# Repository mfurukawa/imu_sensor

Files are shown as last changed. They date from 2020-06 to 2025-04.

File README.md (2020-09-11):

# imu_sensor
Eagle PCB, mbed source code included.

- September 9, 2020 - changed Python code and mbed Protocol / Yuto Nakayachi 
- July  3, 2020 - Python, Unity, C# sample added / Masahiro Furukawa
- June 26, 2020 - created / Masahiro Furukawa

Masahiro Furukawa / Yuto Nakayachi

# mbed Protocol 

# for 4Ch MPU-9250 Sensor Module 

mbed Source Code

https://os.mbed.com/users/nakataniuchi/code/MPU9250_CH4_3_0_0/

see main.cpp

https://os.mbed.com/users/nakataniuchi/code/MPU9250_CH4_3_0_0//file/cdeed96f97fc/main.cpp/

# How to check mbed response

1. Open terminal software.
2. Set baudrate as 921600bps.
3. Set linefeed as “LF” only.
4. Press reset button on mbed.
5. If you see some message, mbed works.
6. Press ‘s’ key and you will see the data stream
7. Press ‘r’ key and it will stop.

# Protocol for ver 3.0.0

Byte order is **Big** Endian

for Header : 1 bytes = 8 bits describes 1 value 

<td>*</td> : header 

for Acceleration  : 2 bytes = 16 bits describes 1 value

Higher Byte 

A<sub>x, i</sub> : acceleration on axis X of ch i

A<sub>y, i</sub> : acceleration on axis Y of ch i 

A<sub>z, i</sub> : acceleration on axis Y of ch i 

Lower Byte

a<sub>x, i</sub> : acceleration on axis X of ch i 

a<sub>y, i</sub> : acceleration on axis Y of ch i 

a<sub>z, i</sub> : acceleration on axis Z of ch i 

for Angular Velocity  : 2 bytes = 16 bits describes 1 value

Higher Byte

W<sub>x, i</sub> : angular velocity on axis X of ch i 

W<sub>y, i</sub> : angular velocity on axis Y of ch i 

W<sub>z, i</sub> : angular velocity on axis Z of ch i 

Lower Byte

w<sub>x, i</sub> : angular velocity on axis X of ch i

w<sub>y, i</sub> : angular velocity on axis Y of ch i

w<sub>z, i</sub> : angular velocity on axis Z of ch i

Time : Time value gives the difference from the previous sequence

Byte Array (52 Bytes = 1 Byte(Header) + 2 Byte * 3(xyz) *2(Acc, Gyro) * 4 (Ch) + 1 Byte(Time value) + 2 Byte(CR, LF) ) :

<table>
  <tr>
   <td>0
   </td>
   <td>1
   </td>
   <td>2
   </td>
   <td>3
   </td>
   <td>4
   </td>
   <td>5
   </td>
   <td>6
   </td>
   <td>7
   </td>
   <td>8
   </td>
   <td>9
   </td>
   <td>10
   </td>
   <td>11
   </td>
   <td>12
   </td>
   <td>13
   </td>
   <td>14
   </td>
   <td>15
   </td>
  </tr>
  <tr>
   <td>*
   </td>
   <td>
   </td>
   <td>
   </td>
   <td>
   </td>
   <td>
   </td>
   <td>
   </td>
   <td>
   </td>
   <td>
   </td>
   <td>
   </td>
   <td>
   </td>
   <td>
   </td>
   <td>
   </td>
   <td>
   </td>
   <td>
   </td>
   <td>
   </td>
   <td>
   </td>
  <tr>
   <td>A<sub>x,1</sub> 
   </td>
   <td>a<sub>x,1</sub> 
   </td>
   <td>A<sub>y,1</sub> 
   </td>
   <td>a<sub>y,1</sub> 
   </td>
   <td>A<sub>z,1</sub> 
   </td>
   <td>a<sub>z,1</sub> 
   </td>
   <td>W<sub>x,1</sub> 
   </td>
   <td>w<sub>x,1</sub>
   </td>
   <td>W<sub>y,1</sub>
   </td>
   <td>w<sub>y,1</sub>
   </td>
   <td>W<sub>z,1</sub> 
   </td>
   <td>w<sub>z,1</sub> 
   </td>
   <td>A<sub>x,<em>2 </em></sub>
   </td>
   <td>a<sub>x,<em>2 </em></sub>
   </td>
   <td>A<sub>y,<em>2 </em></sub>
   </td>
   <td>a<sub>y,<em>2 </em></sub>
   </td>
  </tr>
  <tr>
   <td>A<sub>z,<em>2</em></sub>
   </td>
   <td>a<sub>z,<em>2</em></sub>
   </td>
   <td>W<sub>x,<em>2</em></sub>
   </td>
   <td>w<sub>x,<em>2</em></sub>
   </td>
   <td>W<sub>y,<em>2</em></sub>
   </td>
   <td>w<sub>y,<em>2</em></sub>
   </td>
   <td>W<sub>z,2</sub>
   </td>
   <td>w<sub>z,2</sub>
   </td>
   <td>A<sub>x,3</sub>
   </td>
   <td>a<sub>x,3</sub>
   </td>
   <td>A<sub>y,3</sub>
   </td>
   <td>a<sub>y,3</sub>
   </td>
   <td>A<sub>z,3</sub>
   </td>
   <td>a<sub>z,3</sub>
   </td>
   <td>W<sub>x,3</sub>
   </td>
   <td>w<sub>x,3</sub>
   </td>
  </tr>
  <tr>
   <td>W<sub>y,3</sub>
   </td>
   <td>w<sub>y,3</sub>
   </td>
   <td>W<sub>z,3</sub> 
   </td>
   <td>w<sub>z,3</sub>
   </td>
   <td>A<sub>x,<em>4</em></sub>
   </td>
   <td>a<sub>x,<em>4</em></sub>
   </td>
   <td>A<sub>y,<em>4</em></sub>
   </td>
   <td>a<sub>y,<em>4</em></sub>
   </td>
   <td>A<sub>z,4</sub> 
   </td>
   <td>a<sub>z,4</sub>
   </td>
   <td>W<sub>x,4</sub> 
   </td>
   <td>w<sub>x,4</sub>
   </td>
   <td>W<sub>y,4</sub>
   </td>
   <td>w<sub>y,4</sub>
   </td>
   <td>W<sub>z,4</sub>
   </td>
   <td>w<sub>z,4</sub> 
   </td>
  </tr>
  <tr>
   <td>Time
   </td>
   <td>CR
   </td>
   <td>LF
   </td>
   <td>
   </td>
   <td>
   </td>
   <td>
   </td>
   <td>
   </td>
   <td>
   </td>
   <td>
   </td>
   <td>
   </td>
   <td>
   </td>
   <td>
   </td>
   <td>
   </td>
   <td>
   </td>
   <td>
   </td>
   <td>
   </td>
  </tr>
</table>

## MPU9250.h

16bits(= 2 Bytes) represents one value. Angular velocity represents in the same way. The address below shows data address in MPU-9250 IMU sensor.

> ```
> #define MPUREG_ACCEL_XOUT_H 0x3B
> #define MPUREG_ACCEL_XOUT_L 0x3C
> 
> #define MPUREG_ACCEL_YOUT_H 0x3D
> #define MPUREG_ACCEL_YOUT_L 0x3E
> 
> #define MPUREG_ACCEL_ZOUT_H 0x3F
> #define MPUREG_ACCEL_ZOUT_L 0x40
> 
> 
> #define MPUREG_GYRO_XOUT_H 0x43
> #define MPUREG_GYRO_XOUT_L 0x44
> 
> #define MPUREG_GYRO_YOUT_H 0x45
> #define MPUREG_GYRO_YOUT_L 0x46
> 
> #define MPUREG_GYRO_ZOUT_H 0x47
> #define MPUREG_GYRO_ZOUT_L 0x48
> ```

Thus six unsigned integer (8bit) variales represent three accelerations. Also six unsigned integer (8bit) variables represent three angular velocity. 

> ```
> uint8_t accelerometer_response[6]; 
> uint8_t gyroscope_response[6]; 
> ```

## MPU9250.cpp

> ```
> /*-----------------------------------------------------------------------------------------------
>                                 READ ACCELEROMETER
> usage: call this function to read accelerometer data. Axis represents selected axis:
> 0 -> X axis
> 1 -> Y axis
> > 2 -> Z axis
> 
> void mpu9250_spi::read_acc()
> {
>     //int16_t bit_data;
> //    float data;
> //    int i;
>     ReadRegs(MPUREG_ACCEL_XOUT_H,accelerometer_response,6);    
> //    for(i=0; i<3; i++) {
> //        bit_data=((int16_t)accelerometer_response[i*2]<<8)|accelerometer_response[i*2+1];
> //        data=(float)bit_data;
> //        accelerometer_data[i]=data/acc_divider;
> //        
> //    }
>     
> }
> ```

## main.cpp

> ```
> void eventFunc(void)
> {
>   ...
>     // set header 
>     putc(42,stdout); // * 
>
>     for(int i=0; i<nCh; i++) {
>         for(int j=0; j<6; j++) putc(imu[i]->accelerometer_response[j], stdout);
>         for(int j=0; j<6; j++) putc(imu[i]->gyroscope_response[j],     stdout);
>     }
>     tmp_time = sp_time.read_ms();
>     res_time = tmp_time - past_time;
>     past_time = tmp_time;
>     putc(res_time,stdout); //Time Value 
>     putc(13, stdout);  //0x0d = 13(10) CR（復帰）
>     putc(10, stdout);  //0x0a = 10(10) LF（改行）
> }
> ```

# References

## How to read byte stream with Python

[https://qiita.com/keitasumiya/items/25a707c37a73bfd95bac](https://qiita.com/keitasumiya/items/25a707c37a73bfd95bac)

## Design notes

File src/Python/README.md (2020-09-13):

# imu_sensor/src/Python 

- September 14, 2020 - created / Yuto Nakayachi 

Yuto Nakayachi 

# read_acc_3_0_0.py 

mbedから送られてくるbinaryデータを受け取り、それをcsvファイルに落とすソースファイルです。

計測終了後、read_acc_3_0_0.pyと同階層に生データと実データの2つのCSVファイルが生成されます。

## Usage 
$ python read_acc_3_0_0.py

[以下実行結果]

Start Serial Connection 

ready? --> press s key 

[sキーを押す]

time: [計測にかかった時間が出る]

Start Create CSV File 

[生データのcsvファイルの名前].csv created

[実データのcsvファイルの名前].csv created

Done Create CSV File 

number of data: [計測したサンプル数が出る]

number of byte fail: [byte errorの回数が出る]

number of header fail: [heaedr errorの回数が出る]

END

## Note

binaryデータはread()関数により1Byteずつ受け取ります。

時間計測はmbedが各シーケンスごとに、前のシーケンスから経過した時間を出力する仕様です。(ex. 500Hzならば2msを返す)

print文でリアルタイムでのデータ出力(182~193行)を行うと、End byte set error(129行目の処理)とheader error(143行目)の処理が増加し、シーケンスの抜けが発生する(print文の処理がbinaryデータの受けとりに影響を与える)ため、printでのデータ出力はすべてコメントアウトしてあります。

計測時の時刻を作成するcsvファイルの名前としている(計測時刻が2020/09/14の15:10ならばacc_data20209141510.csvという名前のファイルができる)ため、同時刻に複数回計測を行うと、ファイルは上書きされ、最新のもののみが残ります。よって上書きされたくない場合は、作成したファイルの名前を変える、ファイルの保存場所をread_acc_3_0_0.pyとは別階層にするなどの処理が必要です。

# visualize_acc_3_0_0.py 

read_acc_3_0_0.pyが作ったcsvファイルを折れ線グラフに可視化するソースファイルです。

## Usage 

$ python visualize_acc_3_0_0.py [可視化したいcsvファイルの名前].csv

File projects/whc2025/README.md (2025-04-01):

Masahiro Furukawa, furukawa.masahiro.ist@osaka-u.ac.jp

May 31, 2025

# 結線編

(https://www.youtube.com/watch?v=m93yxsdbYiM)

# 接続編

(https://www.youtube.com/watch?v=eA3sOUAiXbg)

# ログ取得編

(https://www.youtube.com/watch?v=WxdOk1CNL8g)

* mbedソースコード開発環境
https://studio.keil.arm.com/

mbed source must be built on keil

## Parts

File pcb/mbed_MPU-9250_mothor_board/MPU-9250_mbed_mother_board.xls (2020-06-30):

基板名称 |  | MPU-9250_mbed_mothor_board
実装数 |  | 3 | 台
No | 部品分類 | 部品種類 | メーカー名 | メーカー型番 | リファレンス | 使用数 | 実装/未実装 | 必要数量 | 提供部品リスト | 支給形状 | パッケージ | 備考
例 | SMD | チップ抵抗 | KOA | RK73H1JTTD10R0F | R5,R10,R15 | 3 | 実装 | 9 |  | バラ | 1608
1 | DIP | コネクタ | JST | 06FDZ-ST(S) | 06FDZ-ST(S) | 4 | 実装 | 12 |  | バラ |  | Top側に実装
2 | DIP | マイコン | NXP | mbed | LPC1768 | 1 | 実装 | 3 |  | バラ |  | Top側に実装
3 | DIP | コンデンサ |  |  |  | 1 | 実装 | 3 |  | バラ |  | Top側に実装
4 | SMD | バッファ | Texas Instruments | SN74LV541APW | SN74LV541APW | 1 | 実装 | 3 |  | カットリール | TSSOP | Bottom側に実装

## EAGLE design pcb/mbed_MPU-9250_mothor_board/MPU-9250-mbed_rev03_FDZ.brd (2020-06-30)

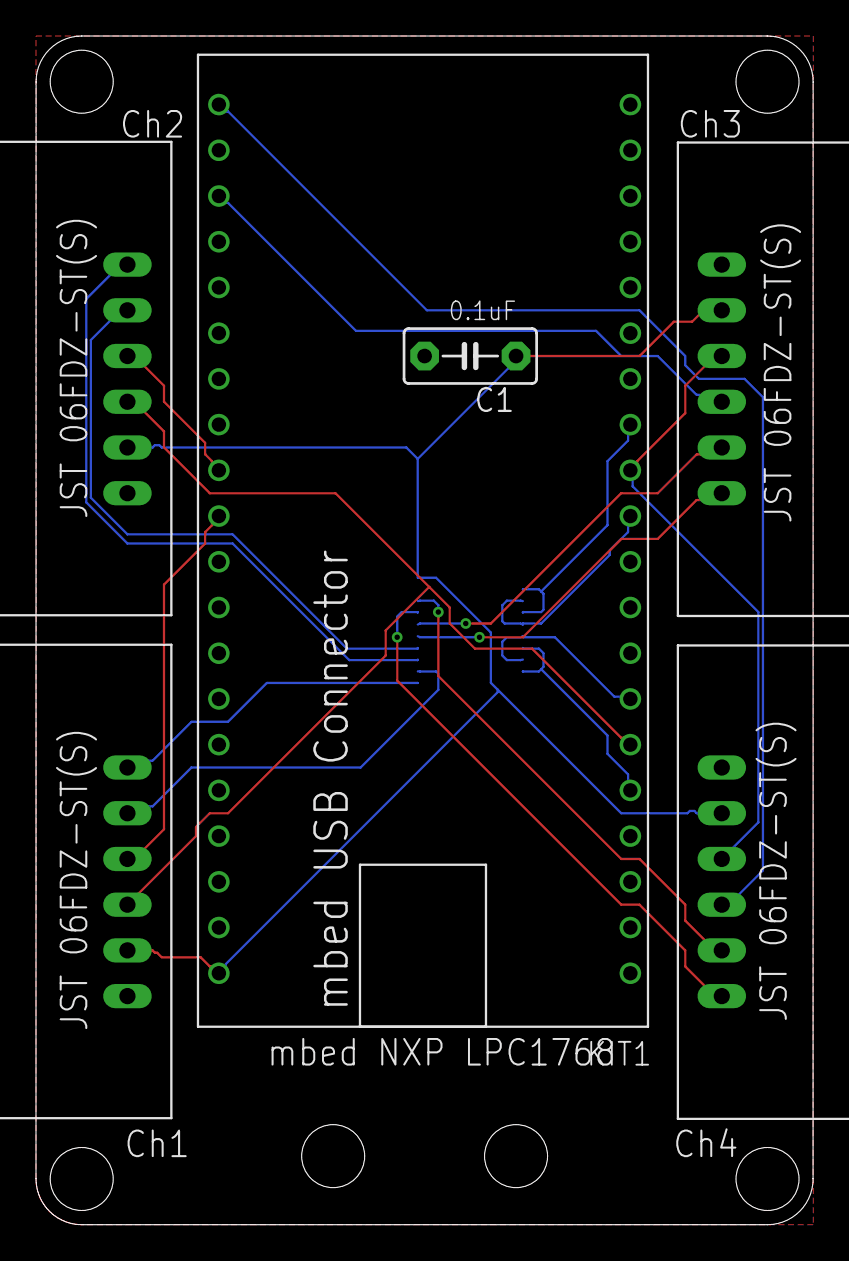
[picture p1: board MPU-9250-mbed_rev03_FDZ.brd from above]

Board: 4 copper layers, 43.2 x 66.0 mm, 7 parts (1 on the bottom side), 20 nets.

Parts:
C1: 0.1u; C5B3
IC1: 74541PW; TSSOP20
KIT1: MBED_NXP_LPC1768; MBED-KIT
U$1, U$2, U$3, U$4: 06FDZ-ST(S)

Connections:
->CLK_SPI1->: IC1.6, IC1.8, KIT1.P$7
->CLK_SPI2->: IC1.2, IC1.4, KIT1.P$13
->MOSI_SPI1->: IC1.7, IC1.9, KIT1.P$5
->MOSI_SPI2->: IC1.3, IC1.5, KIT1.P$11
<-MISO_SPI1<-: KIT1.P$6, U$1.P$3, U$2.P$3
<-MISO_SPI2<-: KIT1.P$12, U$3.P$3, U$4.P$3
CON1_CLK_SPI1: IC1.12, U$1.P$5
CON1_MOSI_SPI1: IC1.11, U$1.P$6
CON2_CLK_SPI1: IC1.14, U$2.P$5
CON2_MOSI_SPI1: IC1.13, U$2.P$6
CON3_CLK_SPI2: IC1.16, U$3.P$5
CON3_MOSI_SPI2: IC1.15, U$3.P$6
CON4_CLK_SPI2: IC1.18, U$4.P$5
CON4_MOSI_SPI2: IC1.17, U$4.P$6
GND: C1.2, IC1.1, IC1.10, IC1.19, KIT1.GND, U$1.P$1, U$2.P$1, U$3.P$1, U$4.P$1
VDD: C1.1, IC1.20, KIT1.VOUT, U$1.P$2, U$2.P$2, U$3.P$2, U$4.P$2
~CS1: KIT1.P$30, U$1.P$4
~CS2: KIT1.P$29, U$2.P$4
~CS3: KIT1.P$23, U$3.P$4
~CS4: KIT1.P$21, U$4.P$4

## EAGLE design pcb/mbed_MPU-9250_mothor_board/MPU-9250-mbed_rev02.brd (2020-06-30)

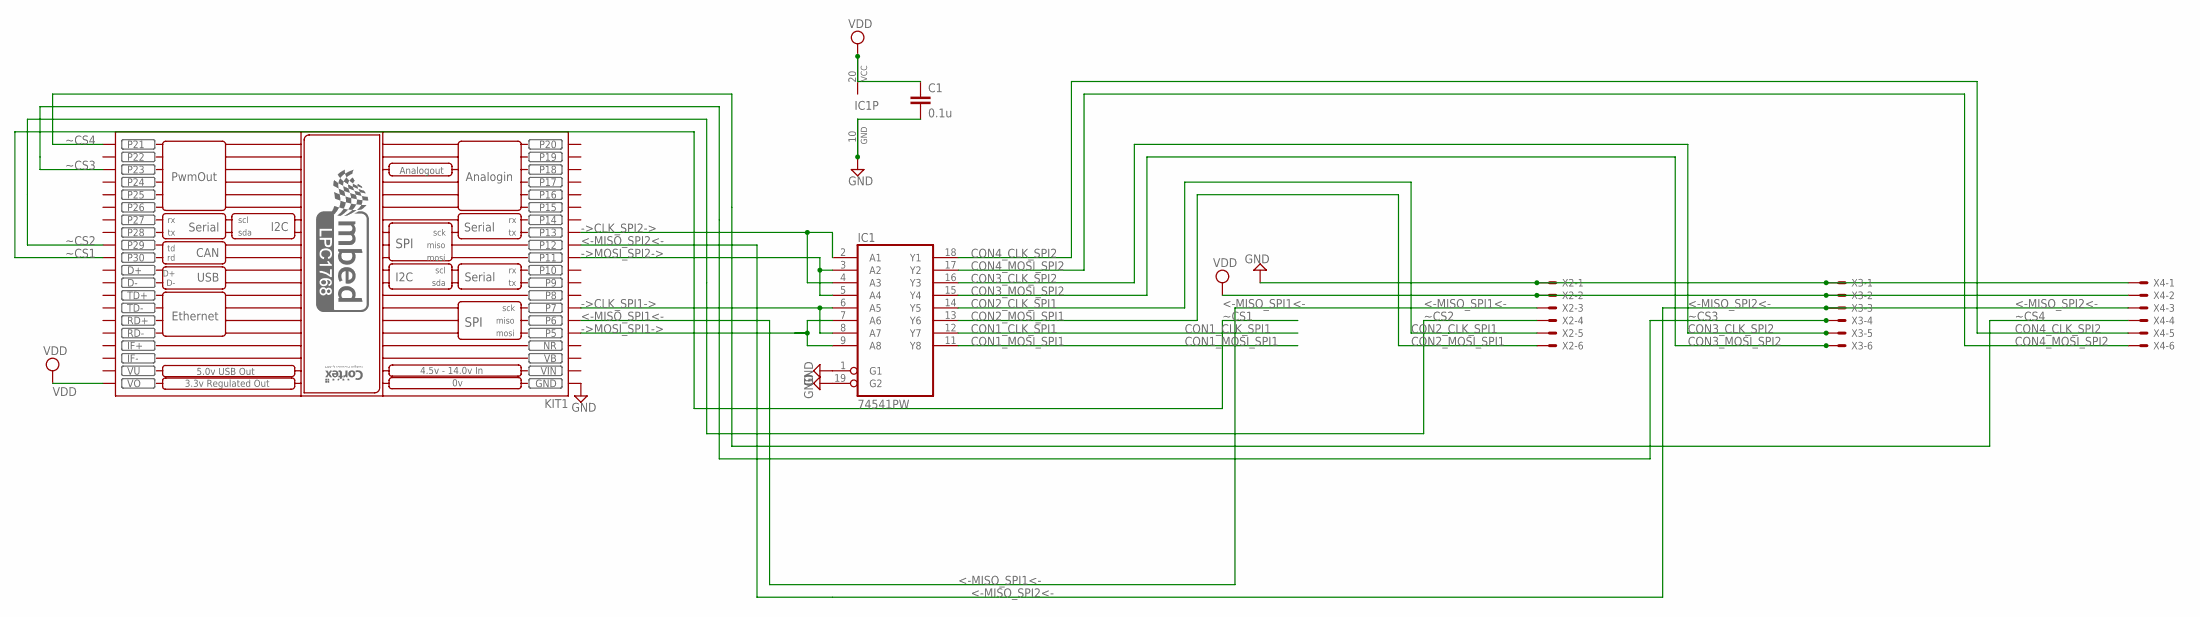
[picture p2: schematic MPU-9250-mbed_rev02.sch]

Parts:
C1: 0.1u; C5B3
IC1: 74541PW; TSSOP20
KIT1: MBED_NXP_LPC1768; MBED-KIT
X2, X3, X4: 22-23-2061

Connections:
->CLK_SPI1->: IC1.6 (A5), IC1.8 (A7), KIT1.P$7 (P7)
->CLK_SPI2->: IC1.2 (A1), IC1.4 (A3), KIT1.P$13 (P13)
->MOSI_SPI1->: IC1.7 (A6), IC1.9 (A8), KIT1.P$5 (P5)
->MOSI_SPI2->: IC1.3 (A2), IC1.5 (A4), KIT1.P$11 (P11)
<-MISO_SPI1<-: KIT1.P$6 (P6), X2.3
<-MISO_SPI2<-: KIT1.P$12 (P12), X3.3, X4.3
CON1_CLK_SPI1: IC1.12 (Y7)
CON1_MOSI_SPI1: IC1.11 (Y8)
CON2_CLK_SPI1: IC1.14 (Y5), X2.5
CON2_MOSI_SPI1: IC1.13 (Y6), X2.6
CON3_CLK_SPI2: IC1.16 (Y3), X3.5
CON3_MOSI_SPI2: IC1.15 (Y4), X3.6
CON4_CLK_SPI2: IC1.18 (Y1), X4.5
CON4_MOSI_SPI2: IC1.17 (Y2), X4.6
GND: C1.2, IC1.1 (G1), IC1.10 (GND), IC1.19 (G2), KIT1.GND, X2.1, X3.1, X4.1
NR: KIT1.NR
VB: KIT1.VB
VDD: C1.1, IC1.20 (VCC), KIT1.VOUT (VO), X2.2, X3.2, X4.2
VIN: KIT1.VIN
VU: KIT1.VU
~CS1: KIT1.P$30 (P30)
~CS2: KIT1.P$29 (P29), X2.4
~CS3: KIT1.P$23 (P23), X3.4
~CS4: KIT1.P$21 (P21), X4.4

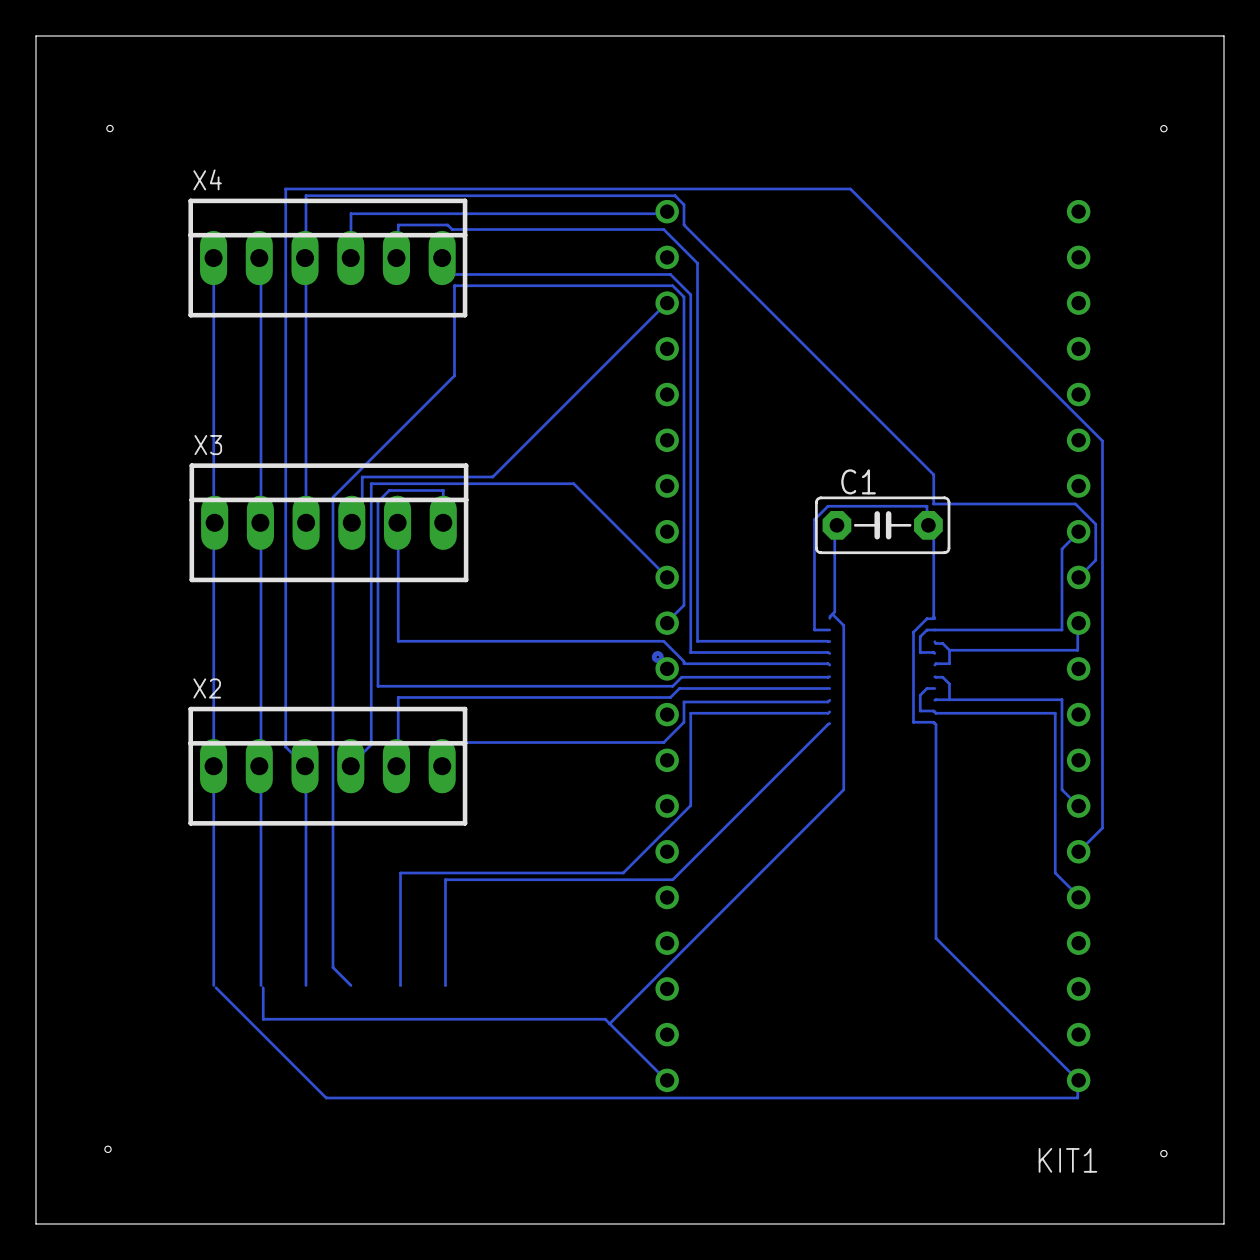
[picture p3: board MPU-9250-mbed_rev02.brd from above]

Board: 2 copper layers, 66.0 x 66.0 mm, 6 parts (1 on the bottom side), 17 nets.

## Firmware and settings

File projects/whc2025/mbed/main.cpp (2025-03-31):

/**
 * Masahiro FURUKAWA - m.furukawa@ist.osaka-u.ac.jp
 *
 * Dec 26, 2017
 * Aug 29, 2018 
 * Dec 17, 2019 @ Digital Low Pass Filter 5Hz -> No LPF
                @ ACC range 2G -> 4G
                @ GYRO range 250 -> 500 Degree per second
                @ Deleted magnet sensor checking 
                @ Set Acc Data Rates, Enable Acc LPF , Bandwidth 218Hz
                @ Use DLPF set Gyroscope bandwidth 5Hz, temperature bandwidth 5Hz
 * Mar 31, 2025 @ Two Channels (Ch2, Ch3), 1kHz for WHC2025
 *
 * MPU9250 9DoF Sensor (Extended to Ch1 ~ Ch4)
 *
 **/

#include "mbed.h"
#include "MPU9250.h"

/* MPU9250 Library
 *
 *  https://developer.mbed.org/users/kylongmu/code/MPU9250_SPI_Test/file/5839d1b118bc/main.cpp
 *
 *   MOSI (Master Out Slave In)  p5
 *   MISO (Master In Slave Out   p6
 *   SCK  (Serial Clock)         p7
 *   ~CS  (Chip Select)          p8 -> p30
 */

// define serial objects
Serial          pc(USBTX, USBRX);

Ticker          ticker;
Timer           timer;

#define nCh     4   // number of ch

float     SampleFreq = 1000.0f;   // [Hz]
unsigned int counter = 0;
unsigned int usCycle = 1000000/SampleFreq ;

int errFlag = 0;

//define the mpu9250 object
mpu9250_spi     *imu[nCh];

// define SPI object for imu objects
SPI             spi1(p5,  p6,  p7);
SPI             spi2(p11, p12, p13);

void init(void)
{
    pc.baud(921600); //921600 / 115200

    imu[0] = new mpu9250_spi(spi1, p30); // Ch1 on PCB
    imu[1] = new mpu9250_spi(spi1, p29); // Ch2 on PCB *spi1*
    imu[2] = new mpu9250_spi(spi2, p23); // Ch3 on PCB *spi2*
    imu[3] = new mpu9250_spi(spi2, p21); // Ch4 on PCB

    for(int i=0; i<nCh; i++) {

        imu[0]->deselect();
        imu[1]->deselect(); // Ch2 on PCB *spi1*
        imu[2]->deselect(); // Ch3 on PCB *spi2*
        imu[3]->deselect();
        
        imu[i]->select();

        //INIT the mpu9250
        //if(imu[i]->init(1,BITS_DLPF_CFG_188HZ)) 
        //if(imu[i]->init(1,BITS_DLPF_CFG_5HZ))
        if(imu[i]->init(1,BITS_DLPF_CFG_256HZ_NOLPF2))
        { 
            printf("\nCH %d ----- Couldn't initialize", i+1);
            wait(10);
        }
        //output the I2C address to know if SPI is working, it should be 104
        printf("\nCH %d ----- WHOAMI = 0x%2x",i+1, imu[i]->whoami());         
               
        if(imu[i]->whoami() != 0x71) {
            printf(" *** ERROR *** Did not respond correctly!");
            errFlag |= 0x01<<(i*2);
        }else{
            printf(" Acc_scale = %u[G] ",   imu[i]->set_acc_scale(BITS_FS_16G));        wait_ms(10);
            printf(" Gyro_scale = %u[DPS]", imu[i]->set_gyro_scale(BITS_FS_2000DPS));   wait_ms(10);
            //printf("AK8963 WHIAM=0x%2x\n",imu[i]->AK8963_whoami());
            
            //if(imu[i]->AK8963_whoami() != 0x48) {
            //    printf(" *** ERROR *** magnetrometer does not respond correctly!\n");
            //    errFlag |= 0x02<<(i*2);
            //}
            
            //imu[i]->AK8963_calib_Magnetometer();
            //wait_ms(10);
        }
    }
    imu[0]->deselect();     
    imu[1]->select();                           // Ch2 on PCB *spi1*
    imu[2]->select();                           // Ch3 on PCB *spi2*
    imu[3]->deselect();
}

void eventFunc(void)
{
    // limitation on sending bytes at 921600bps - 92bits(under 100us/sample)
    // requirement : 1kHz sampling
    // = 921.5 bits/sample
    // = 115.1 bytes/sample
    // = 50 bytes/axis (2byte/axis)
    
    // 2 byte * 6 axes * 2 ch = 24 bytes/sample

    // imu[0]->select();       imu[1]->deselect();
    // imu[2]->select();       imu[3]->deselect();
    
    // imu[0]->read_acc();    imu[0]->read_rot();            
    // imu[2]->read_acc();    imu[2]->read_rot();
    
    // imu[0]->deselect();    imu[1]->select();
    // imu[2]->deselect();    imu[3]->select();
    
    // imu[1]->read_acc();    imu[1]->read_rot();    
    // imu[3]->read_acc();    imu[3]->read_rot();
    
    imu[1]->read_acc();    imu[1]->read_rot();  // Ch2 on PCB *spi1*
    imu[2]->read_acc();    imu[2]->read_rot();  // Ch3 on PCB *spi2*

    // set header 
    putc(127, stdout); // DEL in ascii 
    putc(127, stdout); // DEL in ascii 

    // Ch2(imu[1]) on PCB *spi1*
    // Ch3(imu[2]) on PCB *spi2*
    for(int i=1; i<=2; i++) {
        // 2 byte * 6 axes * 2 ch = 24 bytes/sample
        for(int j=0; j<6; j++) putc(imu[i]->accelerometer_response[j], stdout);
        for(int j=0; j<6; j++) putc(imu[i]->gyroscope_response[j],     stdout);
    }
        
    // send time stamp // 4バイト（ビッグエンディアン）で送信
    //putc((counter >> 24) & 0xFF, stdout); // 最上位バイト
    putc((counter >> 16) & 0xFF, stdout); // 2番目のバイト
    putc((counter >> 8) & 0xFF, stdout);  // 3番目のバイト
    putc(counter & 0xFF, stdout);         // 最下位バイト

    counter++;
}

void set_acc_scale_all(int val){ 
    for(int i=0; i<nCh; i++) {
        imu[0]->deselect();
        imu[1]->deselect();
        imu[2]->deselect();
        imu[3]->deselect();
    
        imu[i]->select();
        imu[i]->set_acc_scale(val);
        wait_ms(2);
    }
}
void set_gyro_scale_all(int val){ 
    for(int i=0; i<nCh; i++) {
        imu[0]->deselect();
        imu[1]->deselect();
        imu[2]->deselect();
        imu[3]->deselect();
    
        imu[i]->select();
        imu[i]->set_gyro_scale(val);
        wait_ms(2);
    }
}
void set_LPF_all(int val){ 
    for(int i=0; i<nCh; i++) {
        imu[0]->deselect();
        imu[1]->deselect();
        imu[2]->deselect();
        imu[3]->deselect();
    
        imu[i]->select();
        imu[i]->init(1, val);  
        wait_ms(2);
    }
}

int main()
{
    // make instances and check sensors
    init();    

    char c;

    while(1) {
        if(pc.readable()) {
            c = pc.getc();

            switch(c){
                
                // reset
                case 'r':
                    ticker.detach();
                    break;
                
                // start sampling
                case 's': 
                    counter = 0;
                    ticker.attach_us(eventFunc, 1000000.0f/SampleFreq);
                    break;

                // set ACC range
                case 'A':
                    ticker.detach();        
                    c = pc.getc();  // read second byte
                    if('0' == c)  set_acc_scale_all(BITS_FS_2G);  
                    if('1' == c)  set_acc_scale_all(BITS_FS_4G);
                    if('2' == c)  set_acc_scale_all(BITS_FS_8G);
                    if('3' == c)  set_acc_scale_all(BITS_FS_16G); 
                    break;

                // set GYRO range
                case 'G':
                    ticker.detach();        
                    c = pc.getc();  // read second byte
                    if('0' == c)  set_gyro_scale_all(BITS_FS_250DPS);  
                    if('1' == c)  set_gyro_scale_all(BITS_FS_500DPS);
                    if('2' == c)  set_gyro_scale_all(BITS_FS_1000DPS);
                    if('3' == c)  set_gyro_scale_all(BITS_FS_2000DPS); 
                    break;

                // set LPF cutoff frequecy
                case 'L':
                    ticker.detach();        
                    c = pc.getc();  // read second byte
                    if('0' == c)  set_LPF_all(BITS_DLPF_CFG_256HZ_NOLPF2);  
                    if('1' == c)  set_LPF_all(BITS_DLPF_CFG_188HZ);
                    if('2' == c)  set_LPF_all(BITS_DLPF_CFG_98HZ);
                    if('3' == c)  set_LPF_all(BITS_DLPF_CFG_42HZ); 
                    if('4' == c)  set_LPF_all(BITS_DLPF_CFG_20HZ);  
                    if('5' == c)  set_LPF_all(BITS_DLPF_CFG_10HZ);
                    if('6' == c)  set_LPF_all(BITS_DLPF_CFG_5HZ);
                    if('7' == c)  set_LPF_all(BITS_DLPF_CFG_2100HZ_NOLPF); 
                    break;

            }
        }
    }
}

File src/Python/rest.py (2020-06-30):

# Masahiro Furukawa
# June 30, 2020

import serial
import time
from struct import *

# ser = serial.Serial('/dev/ttyUSB0', 921600)  
ser = serial.Serial('COM4', 921600,  timeout=1)  

ser.write(b'r')
time.sleep(0.05)

ser.write(b's')
time.sleep(0.05)

state = 0
buf = []

class ACC_GYRO:
    def __int__(self):
        self.ax = 0
        self.ay = 0
        self.az = 0
        self.wx = 0
        self.wy = 0
        self.wz = 0


# data frame    
ch = []
ch.append( ACC_GYRO() )
ch.append( ACC_GYRO() )
ch.append( ACC_GYRO() )
ch.append( ACC_GYRO() )

while 1:

    val = ser.read()
    
    # waiting for '\r'
    if state == 0 and val == b'\r':        
        val = ser.read()
        
        # waiting for '\n' and get ready
        if val == b'\n':
            state = 1
            buf = []
            next
        else:
            print('End byte set failure.')

    # store val into list
    if state == 1:
        buf.append(val)
        
        # decode 48 bytes
        if len(buf) == 48:
            (ch[0].ax, ch[0].ay, ch[0].az, ch[0].wx, ch[0].wy, ch[0].wz,
             ch[1].ax, ch[1].ay, ch[1].az, ch[1].wx, ch[1].wy, ch[1].wz,
             ch[2].ax, ch[2].ay, ch[2].az, ch[2].wx, ch[2].wy, ch[2].wz,
             ch[3].ax, ch[3].ay, ch[3].az, ch[3].wx, ch[3].wy, ch[3].wz )= unpack('hhhhhhhhhhhhhhhhhhhhhhhh', b''.join(buf)) 
            
            print (ch[0].ax, ch[0].ay, ch[0].az, ch[0].wx, ch[0].wy, ch[0].wz,
             ch[1].ax, ch[1].ay, ch[1].az, ch[1].wx, ch[1].wy, ch[1].wz,
             ch[2].ax, ch[2].ay, ch[2].az, ch[2].wx, ch[2].wy, ch[2].wz,
             ch[3].ax, ch[3].ay, ch[3].az, ch[3].wx, ch[3].wy, ch[3].wz ) 
            

            # print(unpack('hhhhhhhhhhhhhhhhhhhhhhhh', b''.join(buf)) )
            
            buf = []
            state = 0            

ser.close()      

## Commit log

2020-06-30 modified .ignore
    [202006302246trial_1_float.csv, 202006302246trial_1_int.csv, 202006302247trial_1_float.csv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]
2020-06-30 python sample added
2020-07-02 (unstable) added C# sample
2020-07-03 added Unity sample
2020-08-11 Colaboratory を使用して作成しました
2020-09-09 Update README.md
    CR-LFを読み出してから、50byte固定長を読み出し、その先頭バイトデータがheaderと一致しているか確認し、一致していれば格納、していなければやり直しという実装にしました。
    追加したheaderは1byteですがCR - LF - Headerと、3byte連続で一致する必要があるため、実質headerが3bytesあるのと同じ実装になります。
2020-09-11 binファイルとpythonファイルを変更しました。
    3つのファイルを追加しました。
    [binファイル]
    mbedのbinファイルを新しいものに変更しました。
    [read_acc_3_0_0.py]
    mbedから送られてくるbinaryデータを受け取り、それをcsvファイルにおとす関数です。
    binaryデータの受け取り方をreadline()関数からread()関数に変更し、1byteずつ読み込むことにしました。
    時間計測を受け手側で行うことをやめ、mbedが計測したものを受け取る形に変更しました。
    リアルタイムでのデータ出力(182~193行)を行うと、End byte set error(129行目の処理)とheader error(14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
    [read_acc_3_0_0.py, visualize_acc_3_0_0.py]
2020-09-13 README.md, main.cppの追加とread_acc_3_0_0.pyの微修正
    [ README.md ]
    pythonファイルについてのREADME.mdをimu_sensor/src/pythonに追加しました。
    [ main.cpp ]
    mbedのmain.cppをimu_sensor/mbed/srcに追加しました。
    [ read_acc_3_0_0.py ]
    writeCSV()関数内で、作成するCSVファイルの名前がtest~.csvになっていたので、acc_data~.csvに変更しました。
    [main.cpp, read_acc_3_0_0.py]
2020-10-01 added acc calibration (under confirmation)
2020-10-01 Update visualize_acc_3_0_0.py
    ・縦軸の物理量の単位（Gとdps）を追加
    ・横軸の単位をmsからsに変更
2024-09-25 Sensor GUI with tkinter
    Designed by Masahiro Furukawa, Implemented by ChatGPT
2024-09-25 added Readme for PCB
2024-09-25 big endien
    ToDo: Sampling Rate is too slow. Gyro Data is not stored.
2024-09-25 rev 1.0 stable 500Hz sampling done
2024-09-26 センサーの取り付けChによらず計測できるようにした
2025-03-31 fixed byte decoder. must fix milli second
    [read_acc_3_0_1_forWHC(2Ch).py]
